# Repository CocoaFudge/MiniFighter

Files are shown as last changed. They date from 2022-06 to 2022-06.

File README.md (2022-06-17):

# MiniFighter
Open source gamepad hitbox layout

This is a PCB based on RP2040 / Pi Pico.

Running GP2040 firmware by the community: https://github.com/OpenStickFoundation/GP2040-CE

The main concept for this board was a very small 'hitbox' style gamepad. The choices made for size, efficiency and functionality all came into effect for this board. It uses LEDs to provide visual feedback and aesthetically please the user whilst retaining functionality.

An open-source Fightstick community can be found here. I'd like to thank them dearly for inspiring this project.
https://discord.gg/vh4wuTj84C

Free to use, replicate and modify.

Free to distribute, copy.

Firmware may be updated late compared to GP2040 updates. BoardConfig.H provided and v0.43 is provided as of 12/6/22.

Pictures below:





Parts required for PCB building:
- Temperature controlled Soldering Iron / Station. (1PC)
- Raspberry Pi Pico (Must be from Raspberry Pi, no clones or derivatives of RP2040 due to pin layout. (1PC)
- Gateron Hot Swap Sockets for MX Switches. (12PCs)
- Tactile buttons, THT, 6mm x 6mm LXW. Height subjective. (7PCs)
- Cherry-MX switches or MX-Style switches. (12PCs)
- Sinoarcade 24mm MX button cap (11PCs) 30mm MX Button cap (1PCs). <- This is an option in aliexpress store, don't press other options to save money.
- M3 Screws. (8Pcs)
- WS2812B (12PCS)
- 100uF / 0.1nF 0402 SMD Capacitor (12PCS)

Note: 
Schematic has the reference and data for the SMT components required. (Capacitors and LEDs).
To export these, please follow this guide. https://github.com/prrvchr/KiCad-BOM-CPL-Plugin

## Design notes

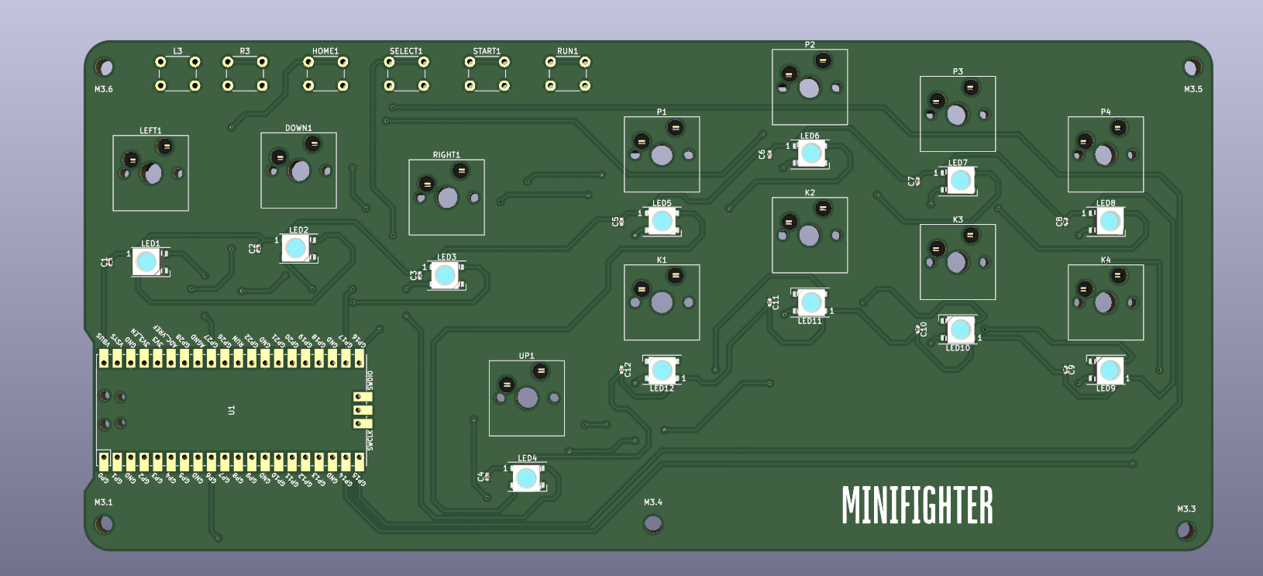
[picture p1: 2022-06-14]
PICS/Screenshot 2022-06-12 031738.png

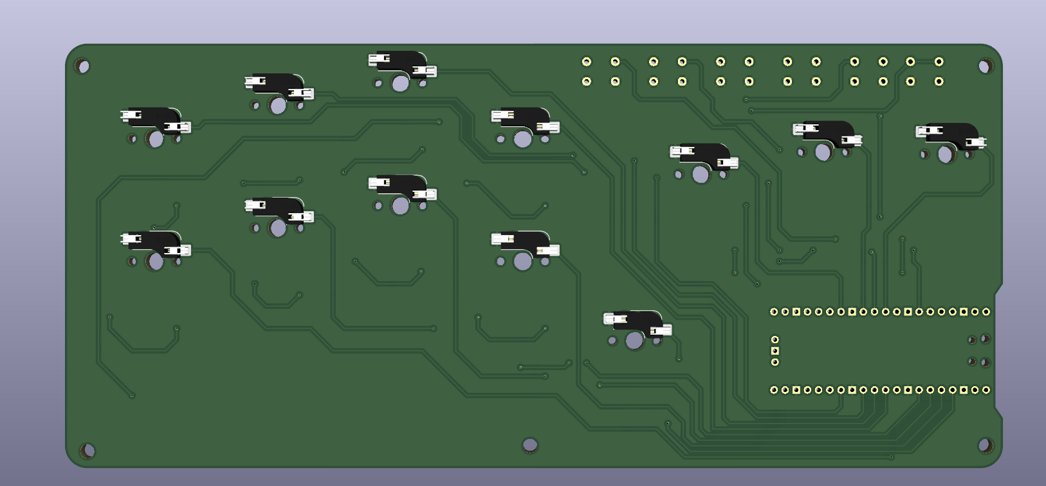
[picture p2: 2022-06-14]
PICS/Screenshot 2022-06-12 031841.png

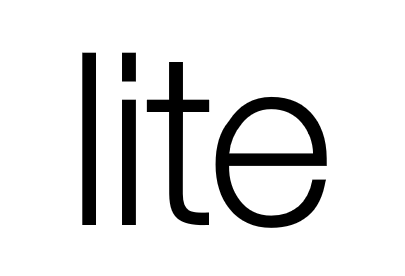
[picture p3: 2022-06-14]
Lite.png

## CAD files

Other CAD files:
KiCad-RP-Pico-main/SketchUp Model/Pico.skp

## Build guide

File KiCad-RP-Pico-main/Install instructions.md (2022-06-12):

# Install instructions

## 1. Copy the files locally

Copy the `RP-Pico Libraries` folder wherever you like on your computer.

## 2. Install the Raspberry Pi Pico board schema symbol

Use the `KiCad | Preferences | Manage Symbol Libraries...` command to manage the symbol library:



then select the global tab and click on the folder button:



navigate to the `RP-Pico Libraries` folder, select the `MCU_RaspberryPi_and_Boards.kicad_sym` file and open it:



et voilà, the first step is completed:



You can now close the symbol libraries manager window.

## 3. Install the Raspberry Pi Pico board footprint

You can use a similar approach to add the footprint to the footprint libraries manager, but I've found some issues that I've solved using the footprint editor, so here are the steps I suggest you to follow:

Open the footprint editor



wait for the footprints to load... then use the `File | Add Library` command:



confirm the `Global` choice:



and select the `MCU_RaspberriPi_and_Boards.pretty` folder (yes, the folder represent a footprint library on KiCad):



Now the library is installed on KiCad with the Raspberry Pi Pico footprint (double click on it to see it on the editor pane):



Don't close the windows as the next step start from here.

## 4. Install the Raspberry Pi Pico board footprint 3D visual

If not already open, open the the footprint editor

symbol library manager

double click on the `RPi_Pico_SMD_TH` footprint from the `MCU_RaspberriPi_and_Boards` library and then click on the `Footprint properties` icon:



In the footprint properties window, first select the `3D Settings` tab. Please note that the preview shows only the PCB board with the footprint added on step 3, without any 3D representation of the Raspberry Pi Pico board. Now click on the folder icon to add the 3D model:



Navigate to the `RP-Pico Libraries` folder, select the `Pico.wrl` file and wait until the model is shown in the right panel, then confirm with OK:



The model is already scaled and translated to match the footprint:



now close the `Footprint Properties` window, and the `Footprint Editor`, obviously saving the changes.

## Conclusion

Now that you've installed the schema and footprint and added the 3D model to the footprint, you can use the Raspberry Pi Pico board on your KiCad projects.

I've also added a test KiCad Project on the `Test` folder, that you can use to see an example of it.

Have fun!

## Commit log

2022-06-12 Initial upload of files
    [MiniFighter.kicad_pcb, MiniFighter.kicad_sch]
2022-06-12 Added files for firmware. PINS and LEDS.
    This is the firmware GP2040 built, and a boardconfig for the changed pin location on PCB, compared to standard pico build.
2022-06-12 Update README.md
    added picture of pin config of GP2040 built-in web configurator app.
2022-06-12 update to files
    added kicad footprints used, parity between local harddrive and internet
    [Pico.skp, Test.kicad_pcb, Test.kicad_sch]
2022-06-12 just refresh
    [MiniFighter.kicad_pcb, MiniFighter.kicad_sch]
2022-06-14 Add files via upload
    Updated the PCB design, made it smaller in dimensions. Button positions and LED placement have NOT CHANGED.
    [MiniFighter.kicad_pcb, MiniFighter.kicad_sch]
2022-06-14 Update README.md
    ADDED NEW SCREENSHOTS OF SHORTER PCB
2022-06-14 Added pictures of new PCB dimensions. LAYOUT SAME
2022-06-14 Smaller Dimensions. LAYOUT NOT CHANGED.
    [MiniFighter.kicad_pcb]
2022-06-15 Fixed GPIO pin assignment to controls
2022-06-16 Fixed GPIO Button assignments.
